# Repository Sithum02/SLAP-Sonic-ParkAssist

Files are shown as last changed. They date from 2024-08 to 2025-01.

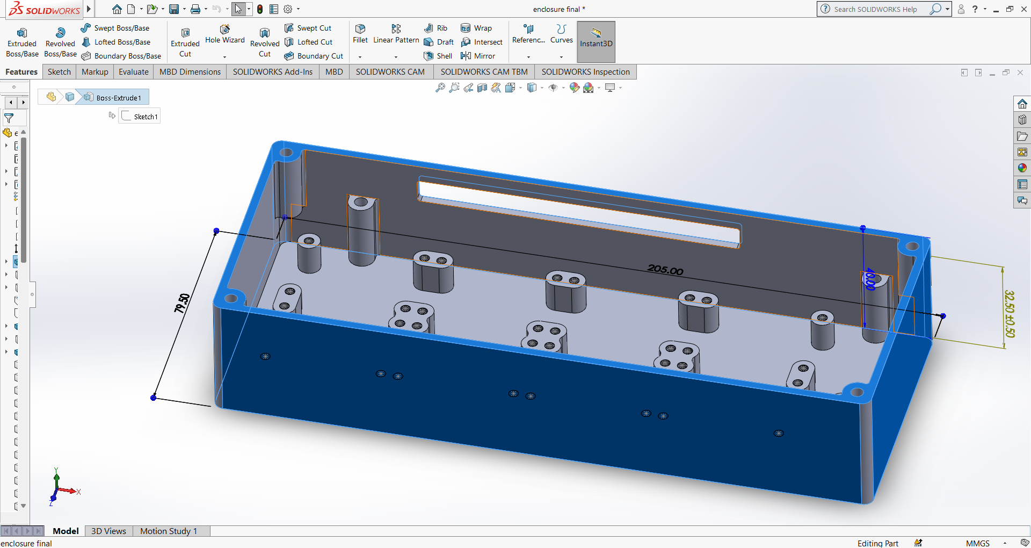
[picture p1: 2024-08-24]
Enclosure/Enclosure Screenshots/Screenshot 2024-08-24 114804.png

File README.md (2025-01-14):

# SLAPSonic ParkAssist

SLAPSonic ParkAssist is an aftermarket parking assist solution designed for vehicles that lack built-in parking sensors. The product provides distance and direction indicators using ultrasonic sensors and buzzers, offering a more intuitive and effective parking experience.

## Project Overview

The SLAPSonic ParkAssist system uses the ATmega328P microcontroller integrated with JSN-SR04T waterproof ultrasonic sensors to measure distances to obstacles and activate buzzers to alert the driver. The system is designed to be easy to install, cost-effective, and reliable for vehicles that require parking assistance.

### Key Features:
- **Microcontroller:** ATmega328P, providing the necessary computing power to handle multiple sensors and buzzers simultaneously.
- **Sensors:** JSN-SR04T waterproof ultrasonic sensors with a wide measuring range and angle.
- **Buzzers:** Active buzzers for audible alerts, with plans to introduce directional tones in future iterations.
- **Enclosure:** Custom-designed enclosure 3D printed in PLA filament, ensuring durability and sleek aesthetics.

### System Components:
- **Power Supply:** LM7805 voltage regulator for stable 12V to 5V conversion.
- **Main PCB:** The PCB connects all modules and integrates the microcontroller.
- **Sensors:** 8 JSN-SR04T sensors to measure distances from obstacles.
- **Buzzers:** Active buzzers for obstacle alerts.

## Features

- **Distance and Direction Alerts:** Provides both distance and direction information using multiple buzzers for clear guidance.
- **Waterproof Sensors:** JSN-SR04T sensors are waterproof, making them suitable for outdoor vehicle installations.
- **Compact and Reliable Design:** The product architecture is designed to reduce size and improve cost-effectiveness for wider adoption.

## Future Improvements

- **PCB Integration:** We aim to integrate the sensor modules directly into the main PCB to reduce the enclosure size and production costs.
- **Injection Molding Enclosure:** Future iterations of the enclosure will be produced using polycarbonate for improved impact and thermal resistance.
- **Microcontroller Upgrade:** Transition to STM microcontrollers for better performance and power management.

## Installation Guide

The SLAPSonic ParkAssist system is designed for easy installation:
1. Mount the ultrasonic sensors at appropriate locations on your vehicle.
2. Connect the sensors and buzzers to the main PCB.
3. Use the provided instructions to install the system and connect it to the vehicle's power supply.
4. Test the system to ensure proper functionality.

## Marketing and Sales

- **Pricing:** SLAPSonic ParkAssist will be sold at Rs. 9,999, offering a competitive and cost-effective solution compared to high-end alternatives.
- **Target Audience:** Our product is designed for drivers of older cars without built-in parking assists, as well as owners of affordable vehicles who want to upgrade their parking capabilities.

## Task Allocation

| Name | Task |
|---|---|
| Attanayake A.Y. | Circuit and PCB design, soldering and troubleshooting |
| De Zoysa A.S.I. | Enclosure design, market analysis, feasibility study |
| Goonetilleke P. | Sensor and buzzer research, microcontroller programming, testing and troubleshooting |
| Perera A.L.C.K. | Enclosure design, overseeing budget, feasibility study, and documentation |

## Budget & Pricing

The initial prototype's cost breakdown is available, with anticipated savings when scaling up production. The final product will be priced at Rs. 9,999, with profit margins aimed at covering development costs and enabling growth.

## Recycling & Disposal

To promote sustainability, we encourage recycling of the product at the end of its lifecycle. We plan to offer incentives to users who return the product’s enclosure for recycling. Detailed disposal instructions for electronic components will be provided to ensure proper environmental impact reduction.

## References

- [Real-world effects of rear automatic braking and other backing assistance systems](https://doi.org/10.1016/j.jsr.2018.12.005) - Journal of Safety Research, 2019.

## License

This project is open-source and licensed under the MIT License. Feel free to contribute and modify the project according to the license terms.

## Contact

For any questions or inquiries, feel free to reach out to the team:

- **Attanayake A.Y.**
- **De Zoysa A.S.I.**
- **Goonetilleke P.**
- **Perera A.L.C.K.**

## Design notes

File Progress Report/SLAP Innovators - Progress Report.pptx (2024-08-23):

## SLAP INNOVATORS

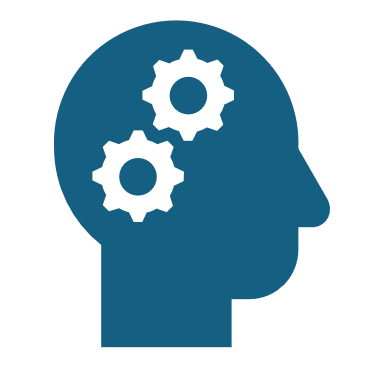
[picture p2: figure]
Head with Gears

Audio-Feedback Based Parking Assist System

## Problem Statement

Problem : Lack of blind spot coverage in most modern and older cars
Solution : Audio-Feedback based parking assist system

## Justification

Market survey results show that the problem exists

## Justification

- Survey also shows that investors are willing to invest in our product

## Task Allocation

Sithum – Designing Enclosure, Marketing
Lahiru – Designing Enclosure, Overseeing Budget
Amoda – Designing PCB, Power Supply
Pravindu – Sensors, Buzzers, and Microcontrollers

## Block Diagram

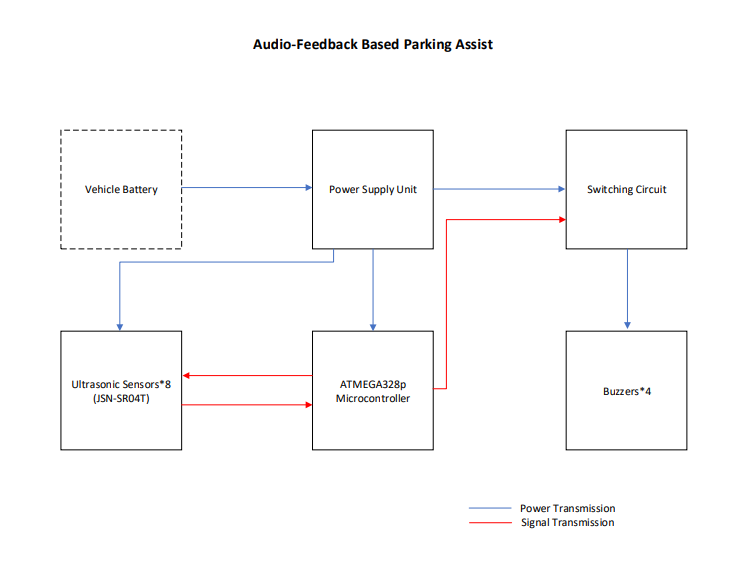
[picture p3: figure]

## Power Supply

Directly from brake lights
Maximum power consumption : (3W) 5V/0.6A

## PCB

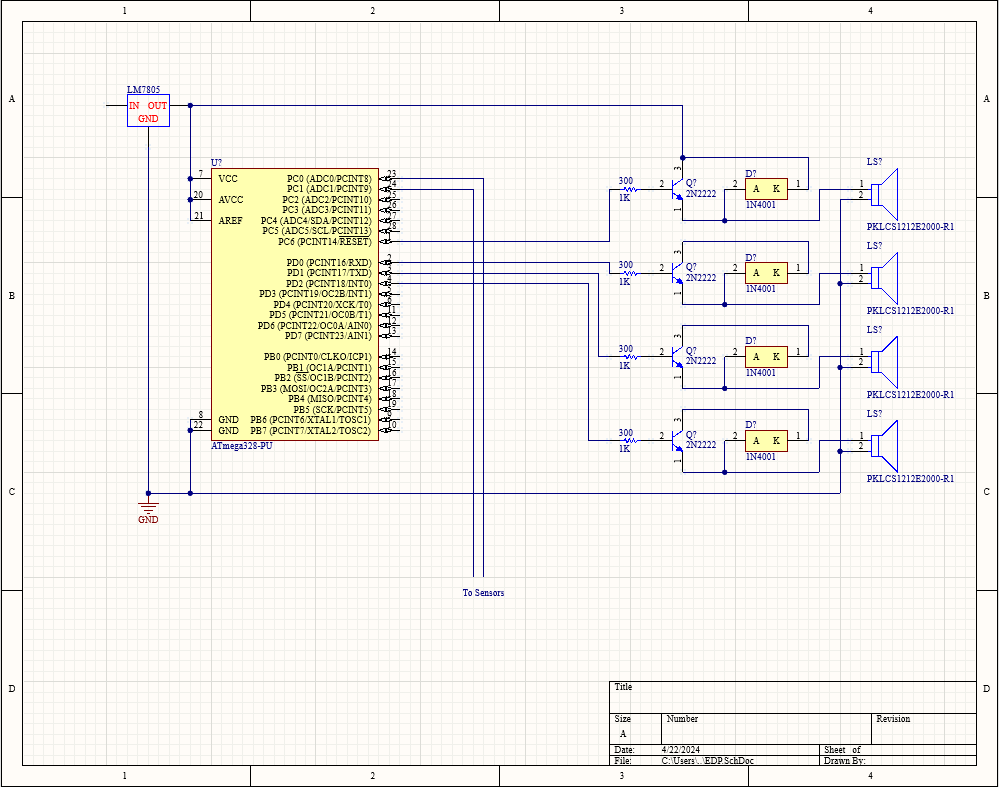
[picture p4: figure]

## Sensor

- Sensor : JSN-SR04T
- Initial testing conducted
  - Capabilities and restraints identified
  - Measurements accurate to a couple of cm
- Waterproof
- Will be attached to vehicles by drilling holes in the bumper

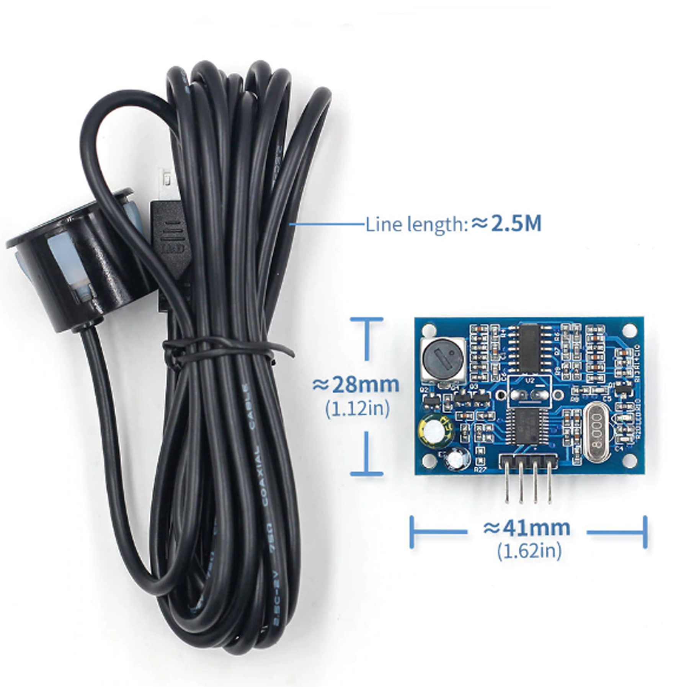
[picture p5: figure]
JSN-SR04T Waterproof Ultrasonic Sensor – Digitalelectronics.lk

## Mounting

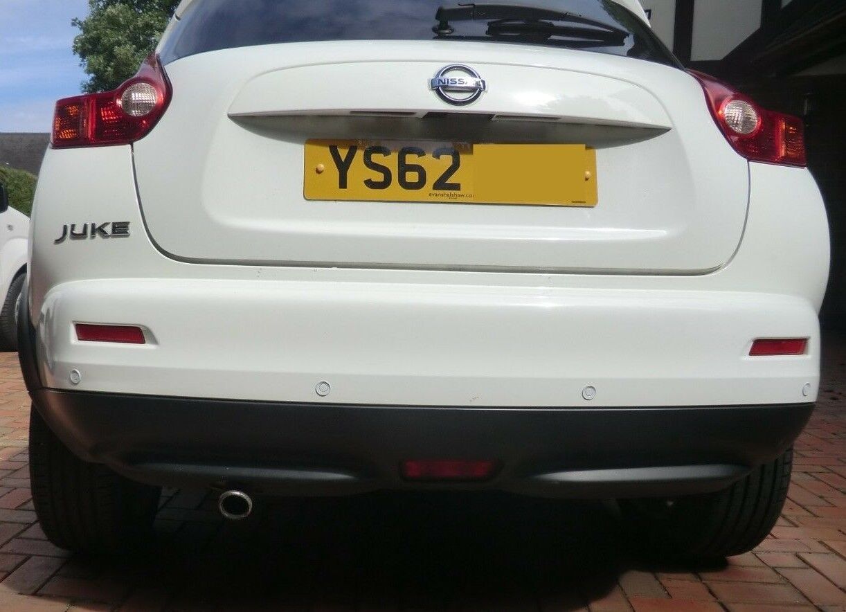
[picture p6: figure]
4 WAY REAR PARKING SENSORS NISSAN JUKE SUPPLIED & FITTED MIDLANDS AREA | eBay

## Microcontroller

- Microcontroller : ATMEGA328p
  - Low cost
  - Low power consumption
  - Sufficient i/o ports

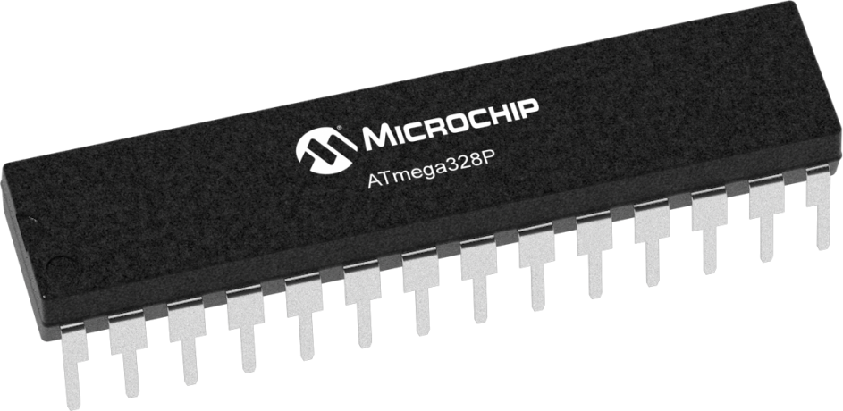
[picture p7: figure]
Programming ATmega328P with Arduino | by Krishna Ojha | Medium

## Enclosure : Initial Design

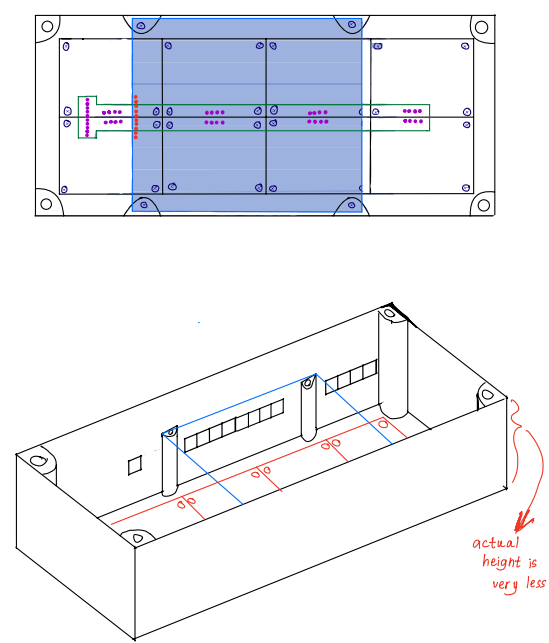
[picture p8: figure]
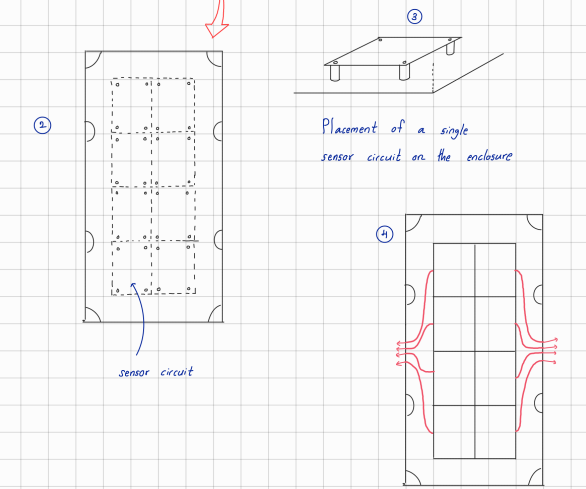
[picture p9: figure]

## Budget/BOQ

No. | Item | Qty | Rate (Without Shipping) | Total Cost
1 | JSN_SR04T | 8 | 542 | 4336
2 | ATMEGA328 | 1 | 750 | 750
3 | PCB | 2 | 250 | 500
4 | Enclosure | 1 | 2500 | 2500
5 | Buzzers | 4 | 400 | 1600
6 | Voltage Regulator | 1 | 70 | 70
| TOTAL | | | 9756

## Technical Feasibility

- Resource requirements can be met within budget
  - Bulk pricing and low-cost equipment
- Performance criteria
  - Sensors are accurate to within 1cm
  - Sensor range from 20 cm – 450 cm
  - Buzzers loud enough to be heard from all ends
  - Testing the sensor sensitivity

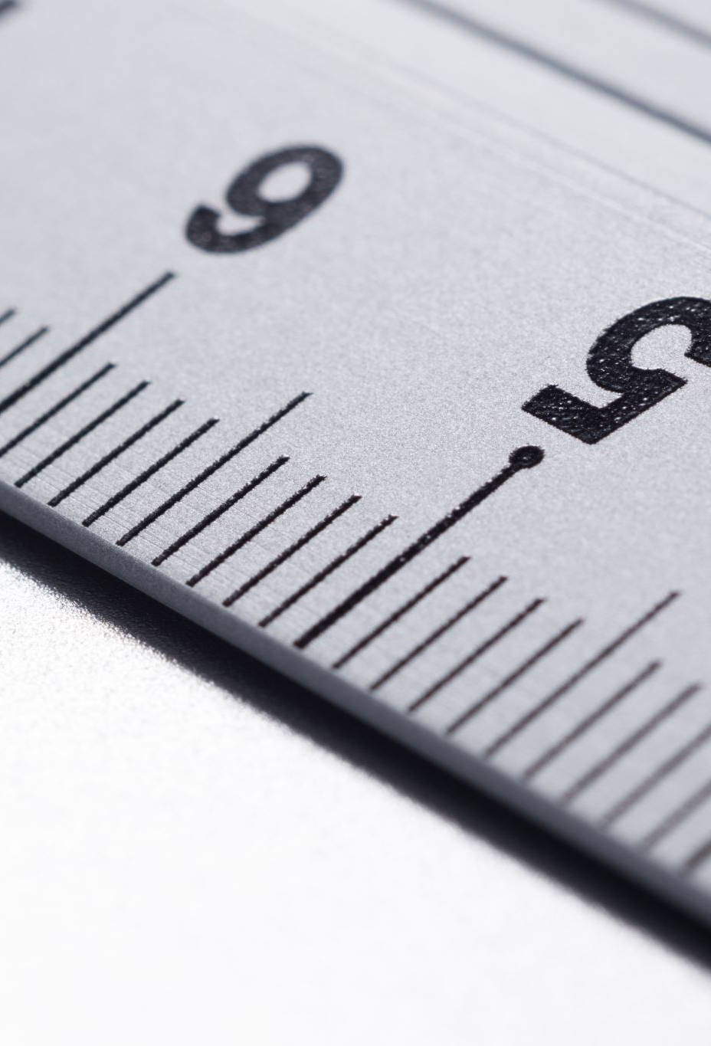
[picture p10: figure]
Close up of ruler

## Marketing and Sales Strategy

- Packaging : Matte plastic. Colors TBD.
- Through direct sales and partnerships with vehicle service stations, vehicle accessory shops etc.
- Marketing through ads on social media platforms.
- Will be made of reusable materials. Discount on next purchase for in exchange for used items older than 7 years.
- Post Sale Services
  - Repair and troubleshooting
  - 3 years warranty

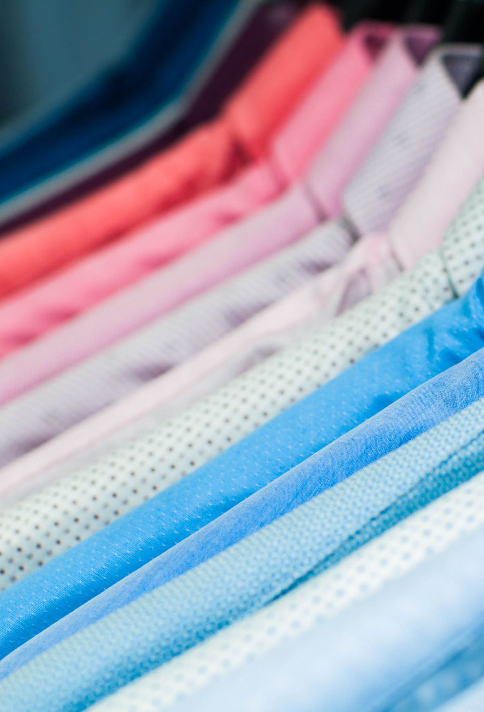
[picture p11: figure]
Multi coloured shirts hanging on the closet

## Thank You

SLAP Innovators

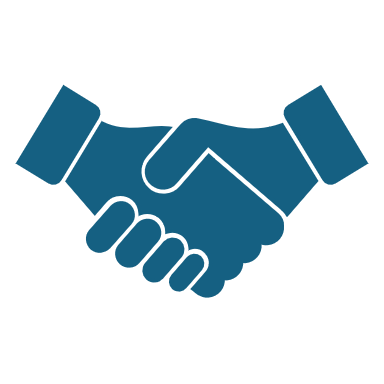
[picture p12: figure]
Handshake

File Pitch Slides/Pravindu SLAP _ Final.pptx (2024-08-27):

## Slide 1

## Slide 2

Just for
Rs. 9,999

Wide Field of View

8 Strategically placed sensors for optimal obstacle detection

4 Directional Audio Alerts

Provides intuitive driver guidance

Compact Design

Simple & easy installation in any vehicle

Lower Power Consumption

Energy efficient for sustainability

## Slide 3

Just for
Rs. 9,999

Wide Field of View

8 Strategically placed sensors for optimal obstacle detection

4 Directional Audio Alerts

Provides intuitive driver guidance

Compact Design

Simple & easy installation in any vehicle

Lower Power Consumption

Energy efficient for sustainability

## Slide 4

Wide Field of View

8 Strategically placed sensors for optimal obstacle detection

4 Directional Audio Alerts

Provides intuitive driver guidance

Compact Design

Simple & easy installation in any vehicle

Lower Power Consumption

Energy efficient for sustainability

Just for
Rs. 9,900

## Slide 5

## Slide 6

Wide Field of View

8 Strategically placed sensors for optimal obstacle detection

4 Directional Audio Alerts

Provides intuitive driver guidance

Compact Design

Simple & easy installation in any vehicle

Lower Power Consumption

Energy efficient for sustainability

Just for
Rs. 9,900

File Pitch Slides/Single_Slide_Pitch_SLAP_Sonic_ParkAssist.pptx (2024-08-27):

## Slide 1

Wide Field of View

8 Strategically placed sensors for optimal obstacle detection

4 Directional Audio Alerts

Provides intuitive driver guidance

Compact Design

Simple & easy installation in any vehicle

Lower Power Consumption

Energy efficient for sustainability

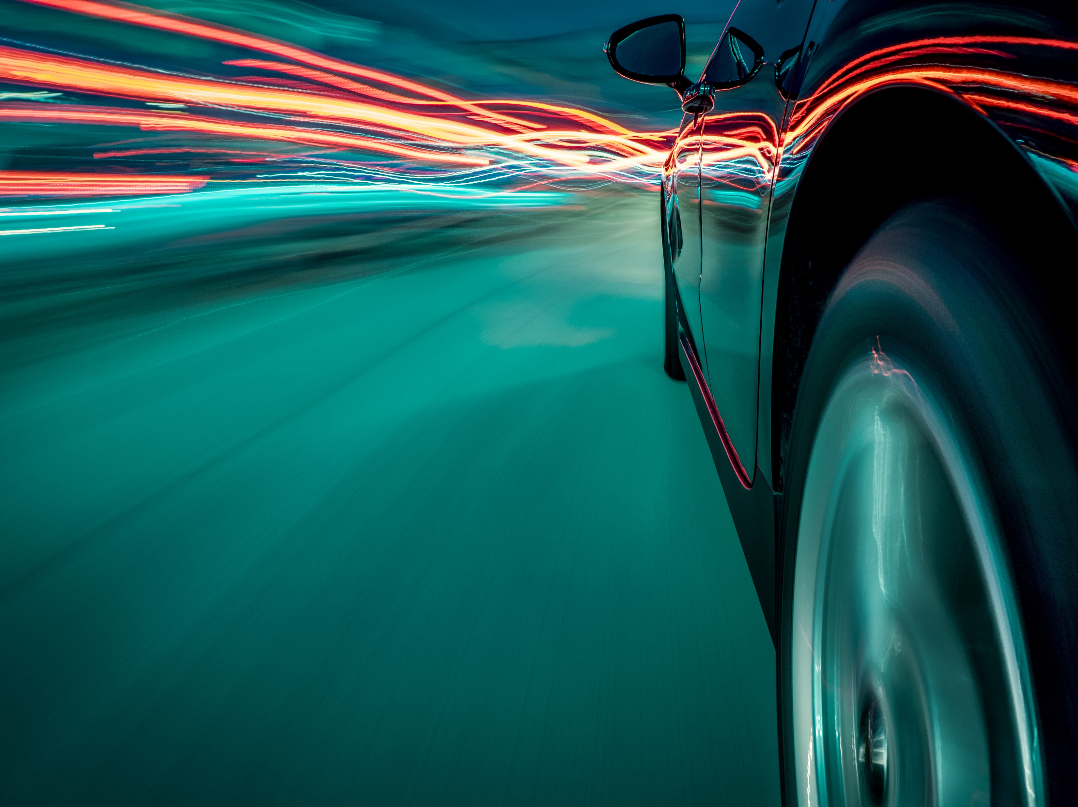
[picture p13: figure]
Long-exposure photo of car in traffic
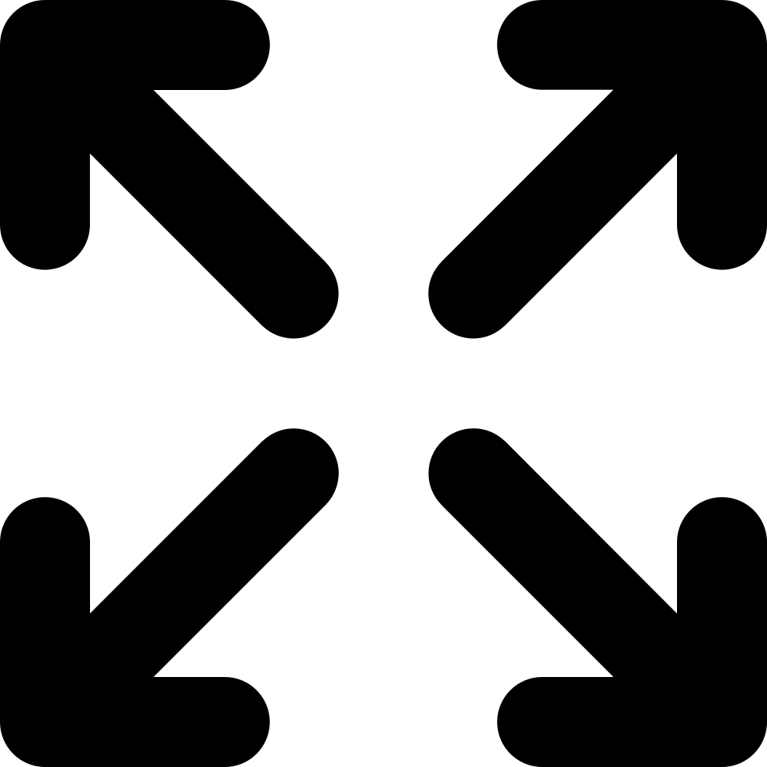
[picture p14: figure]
Font,Line,Clip art,Hand,Graphics,Symbol,Gesture #141486 - Free Icon Library
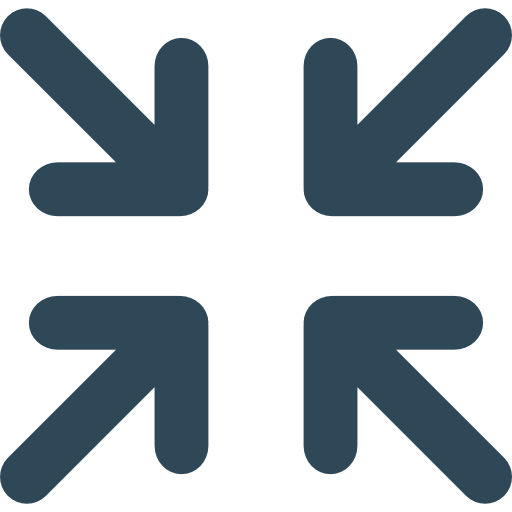
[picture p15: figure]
Anurav Hydronics
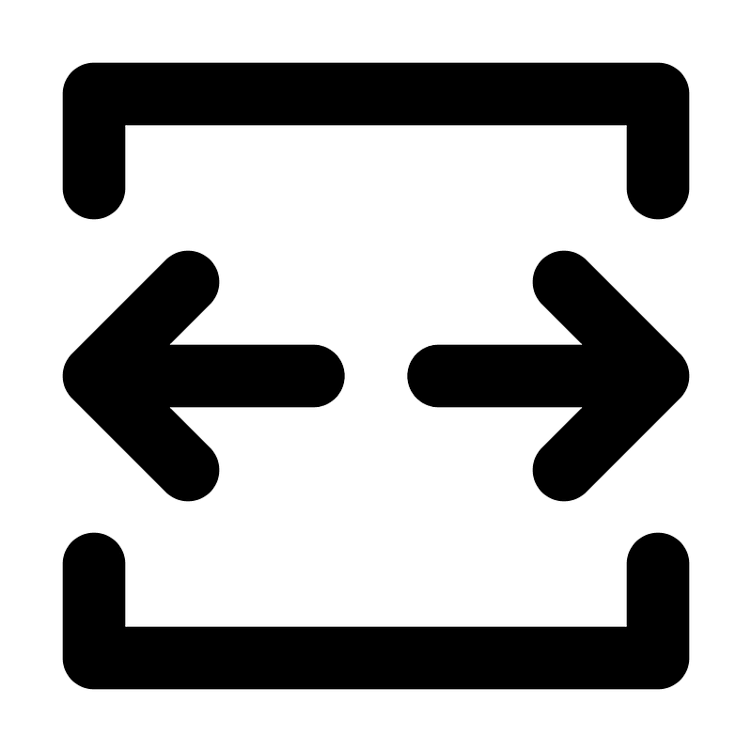
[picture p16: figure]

Just for
Rs. 9,900

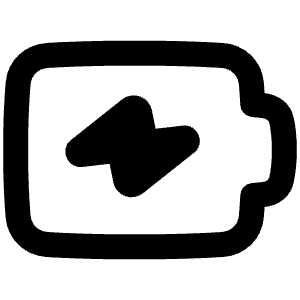
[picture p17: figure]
Battery Charging icon from Plump Remix - Free Set | Free Download as ...

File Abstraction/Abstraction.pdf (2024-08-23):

Power Supply Unit

ATMEGA328p
Microcontroller

Ultrasonic Sensors*8
(JSN-SR04T) | Buzzers*4
Vehicle Battery | Switching Circuit

## Audio-Feedback Based Parking Assist

Power Transmission
Signal Transmission

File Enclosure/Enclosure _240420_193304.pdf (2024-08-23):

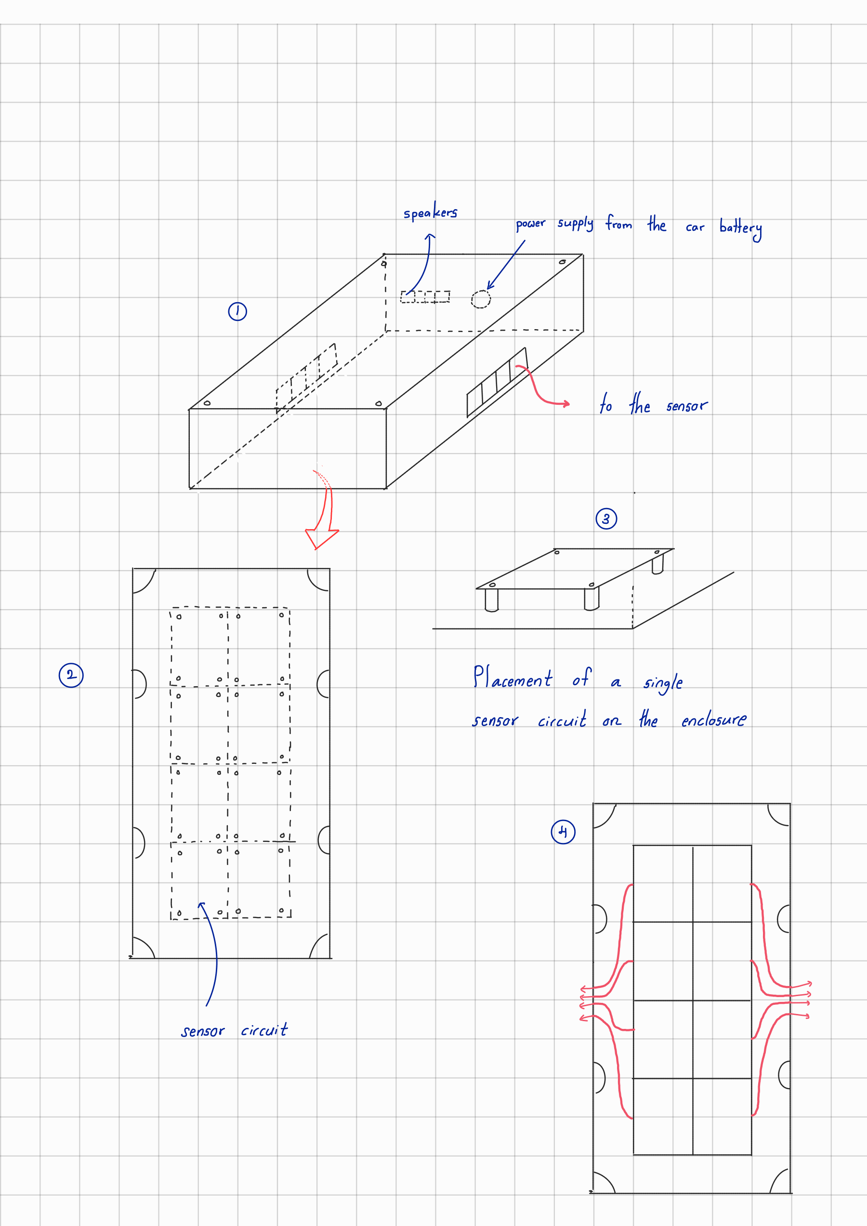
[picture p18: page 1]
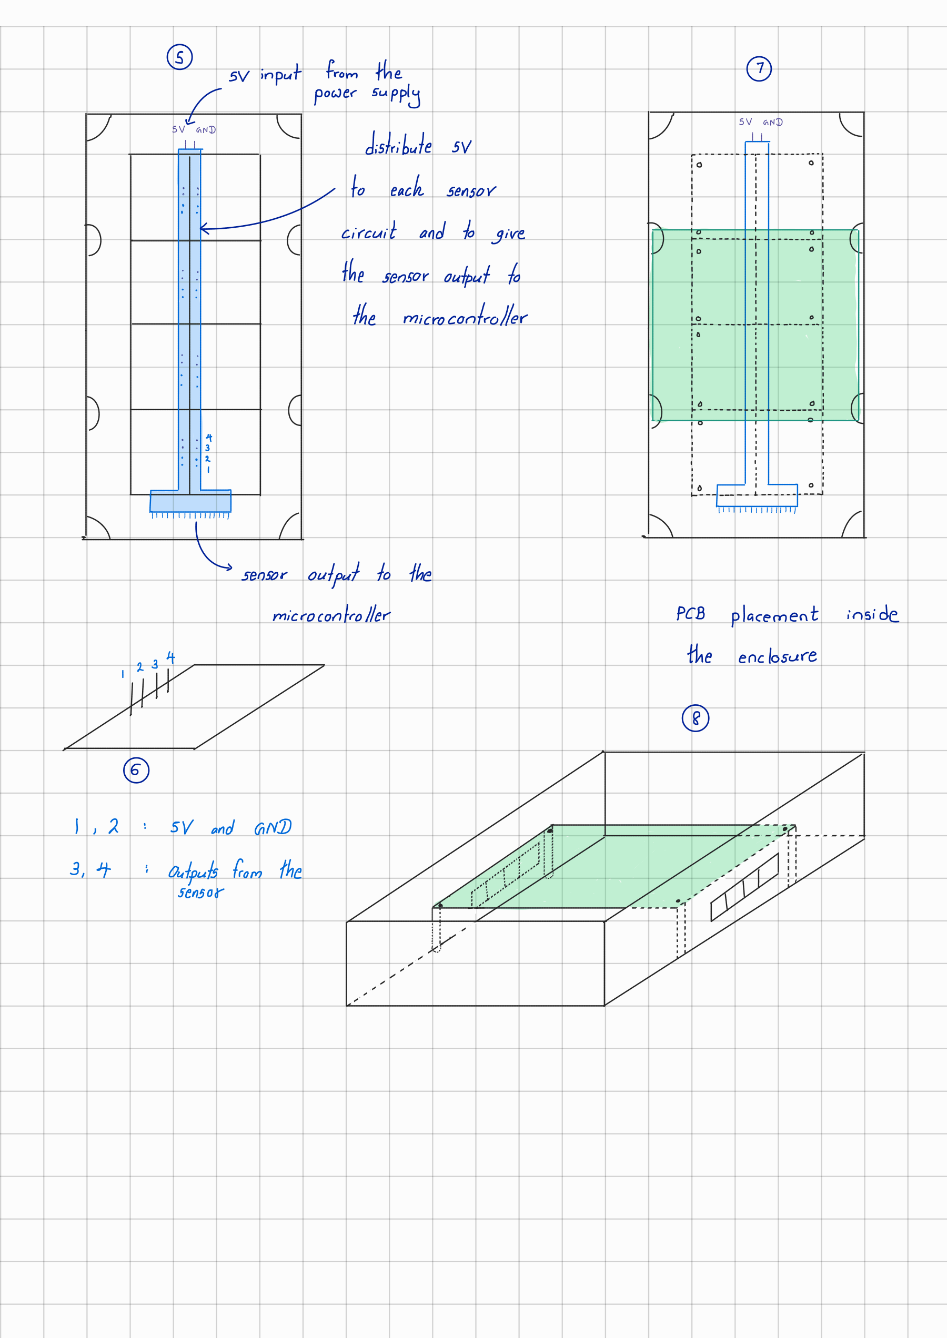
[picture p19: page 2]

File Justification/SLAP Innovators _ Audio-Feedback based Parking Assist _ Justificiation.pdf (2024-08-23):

SLAP Innovators

Justification for the Audio-Feedback based Parking Assist

Introduction

In the realm of automotive safety, the issue of blind spots poses a significant concern. Despite the presence of mirrors, certain areas around a vehicle remain unseen, potentially leading to accidents involving pedestrians or objects. While parking cameras have been introduced to mitigate this risk, their efficacy in reducing accidents remains limited, with a mere 5% improvement. Conversely, integrating parking assist systems has shown a remarkable 42% reduction in parking-related incidents.

Recognizing a gap in the market, particularly among older generation vehicles lacking built-in proximity sensors, our solution aims to address this safety concern. Existing external proximity sensor options typically lack auditory feedback, presenting a challenge for drivers navigating parking and congested traffic situations. Our product offers a tailored solution - an audio-feedback based parking assist system, adaptable to vehicles without built-in proximity alarms.

Functionality

Powered by the vehicle's battery, our system triggers a buzzer or siren when the vehicle nears a solid object. The alarm distance is customizable during installation to suit individual preferences. Four sirens/buzzers positioned at each corner of the vehicle activate upon detecting a barrier, intuitively guiding the driver away from potential hazards.

Justification

Conducting thorough market research, we discovered a prevalent need for parking assistance among respondents.

0.00%

10.00%

20.00%

30.00%

40.00%

50.00%

60.00%

70.00%

80.00%

90.00%

Yes | No | Yes | No
Does your car have Parking Assist | Does your car have Blind Spots

### Current State of Safety Features

The survey overwhelmingly favored the implementation of parking assist systems for both parking and navigating congested traffic scenarios, irrespective of whether they had experienced accidents due to blind spots.

Our survey also revealed a clear preference for audio-feedback based systems, with a significant amount of respondents being willing to invest between Rs. 8,000 and Rs. 10,000. This aligns seamlessly with our product's offerings and market positioning.

0.00%

20.00%

40.00%

60.00%

80.00%

100.00%

120.00%

Yes | No | Yes | No | Yes | No

Have you ever met with an
accident while parking, due
to these blind spots?

Do you think a parking
assist system could help in parking?

Do you think proximity
based parking assists could help to navigate when
stuck in heavy traffic?

### Requirement of a Parking Assist System

0.00%

10.00%

20.00%

30.00%

40.00%

50.00%

60.00%

70.00%

80.00%

90.00%

100.00%

Yes | No

Would you prefer the parking assist to indicate the direction of proximity through speakers placed in the corresponding directions?

### Preferred Assist System

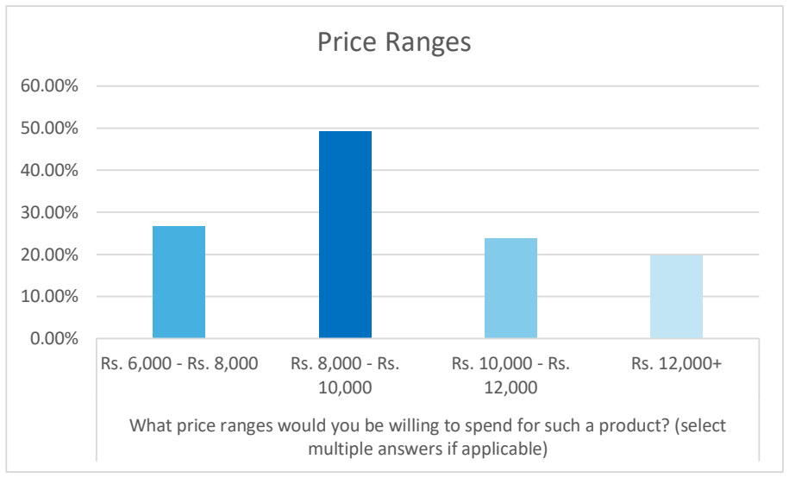
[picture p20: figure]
multiple answers if applicable); Price Ranges

In summary, the demand for our audio-feedback based parking assist system, along with the willingness of consumers to invest in such technology, highlights the tangible market potential for our product.

SLAP Innovators

1. A. Y. Attanayake 220051D
2. A. S. I. De Zoysa 220106D
3. P. Goonetilleke 220183H
4. A. L. C. K. Perera 220495K

What price ranges would you be willing to spend for such a product? (select

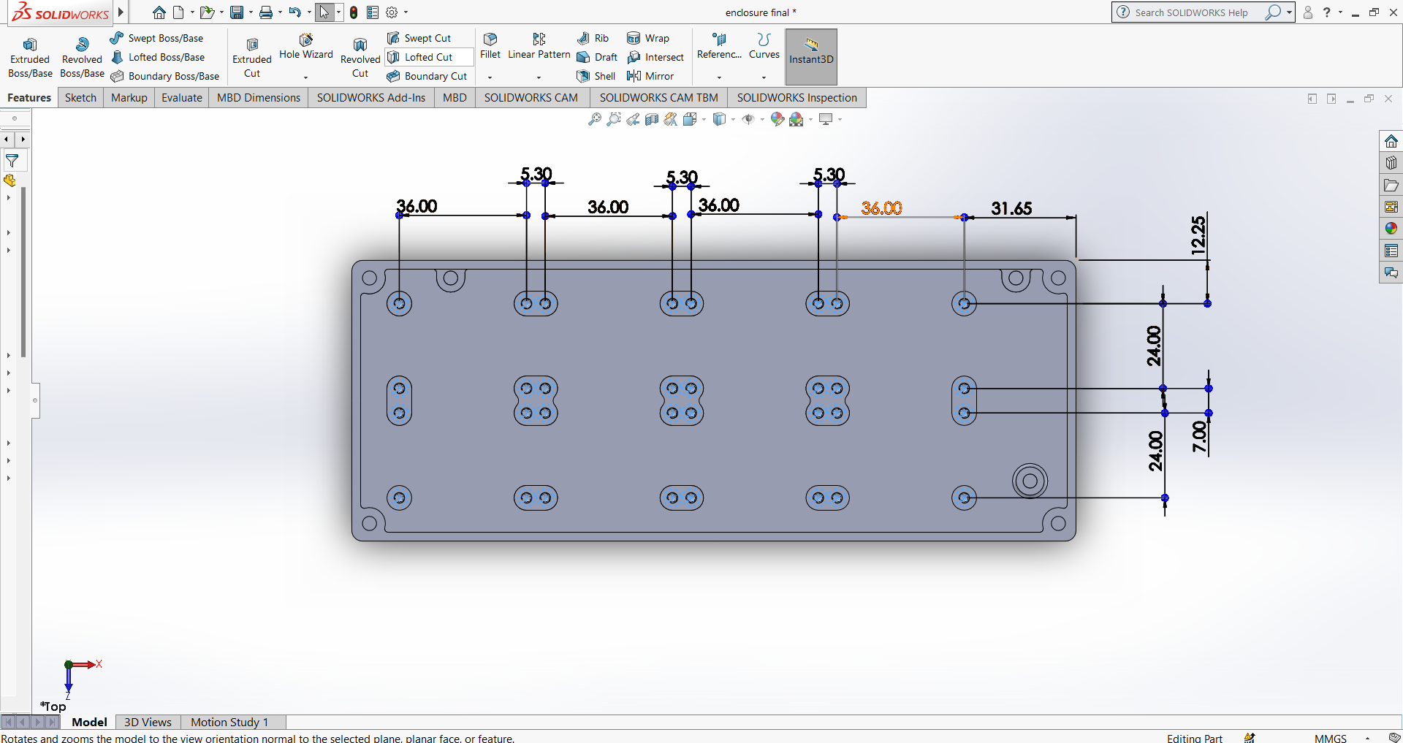
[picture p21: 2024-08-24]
Enclosure/Enclosure Screenshots/Screenshot 2024-08-24 115512.png

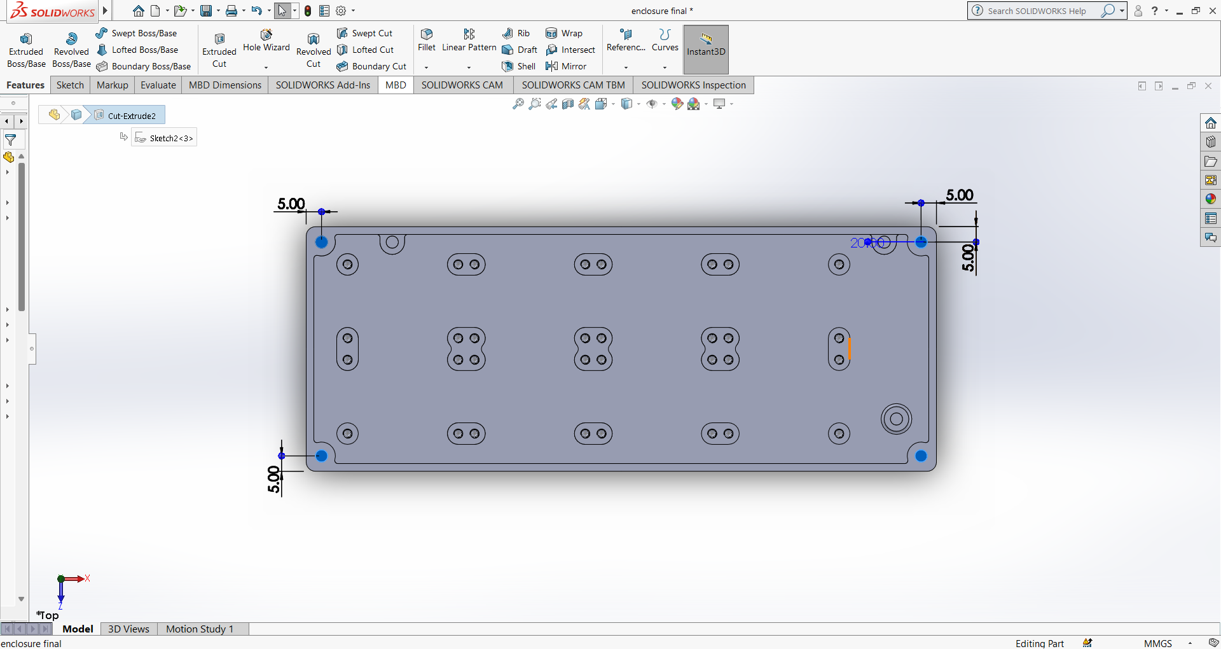
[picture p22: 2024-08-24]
Enclosure/Enclosure Screenshots/Screenshot 2024-08-24 115445.png

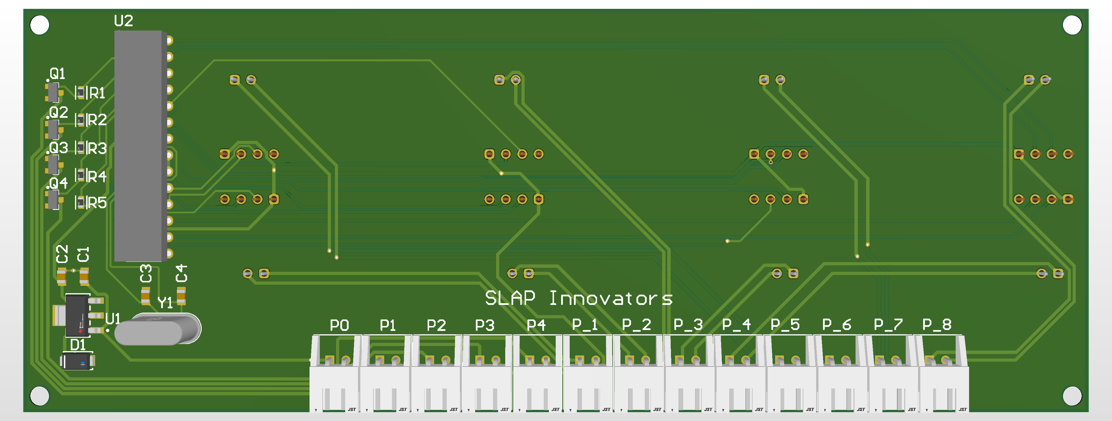
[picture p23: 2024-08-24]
PCB/PCB-Top.png

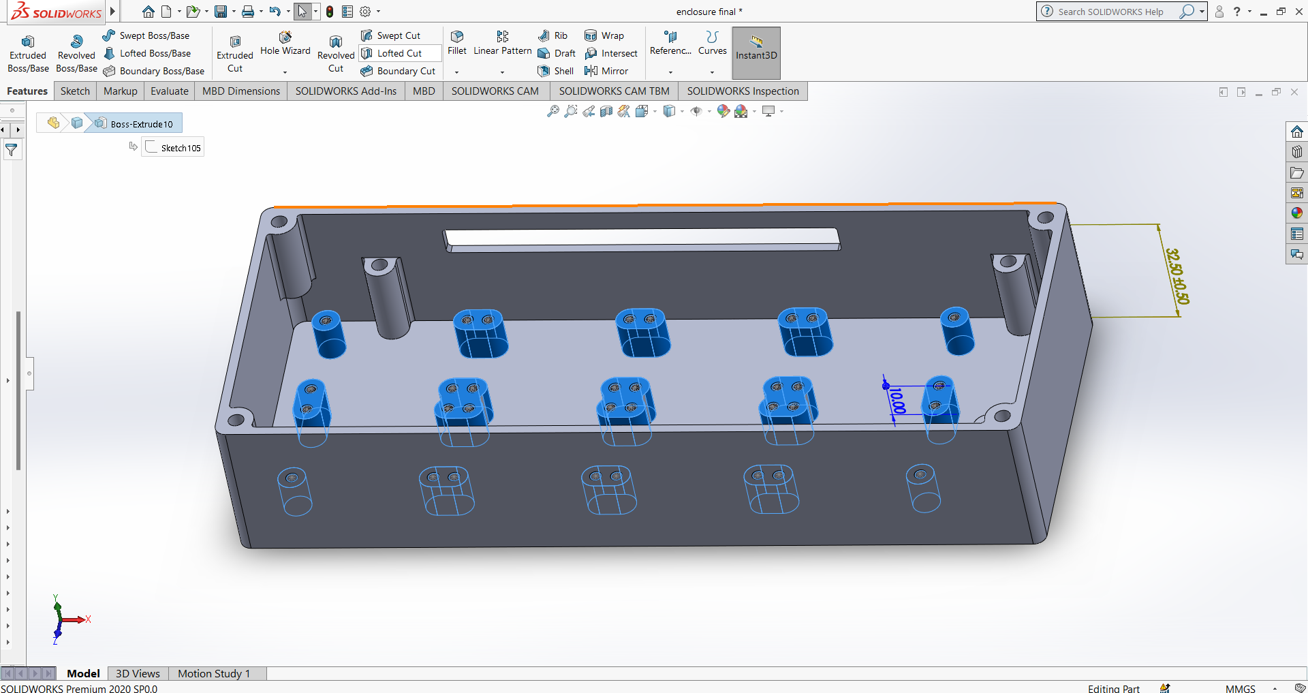
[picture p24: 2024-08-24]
Enclosure/Enclosure Screenshots/Screenshot 2024-08-24 115649.png

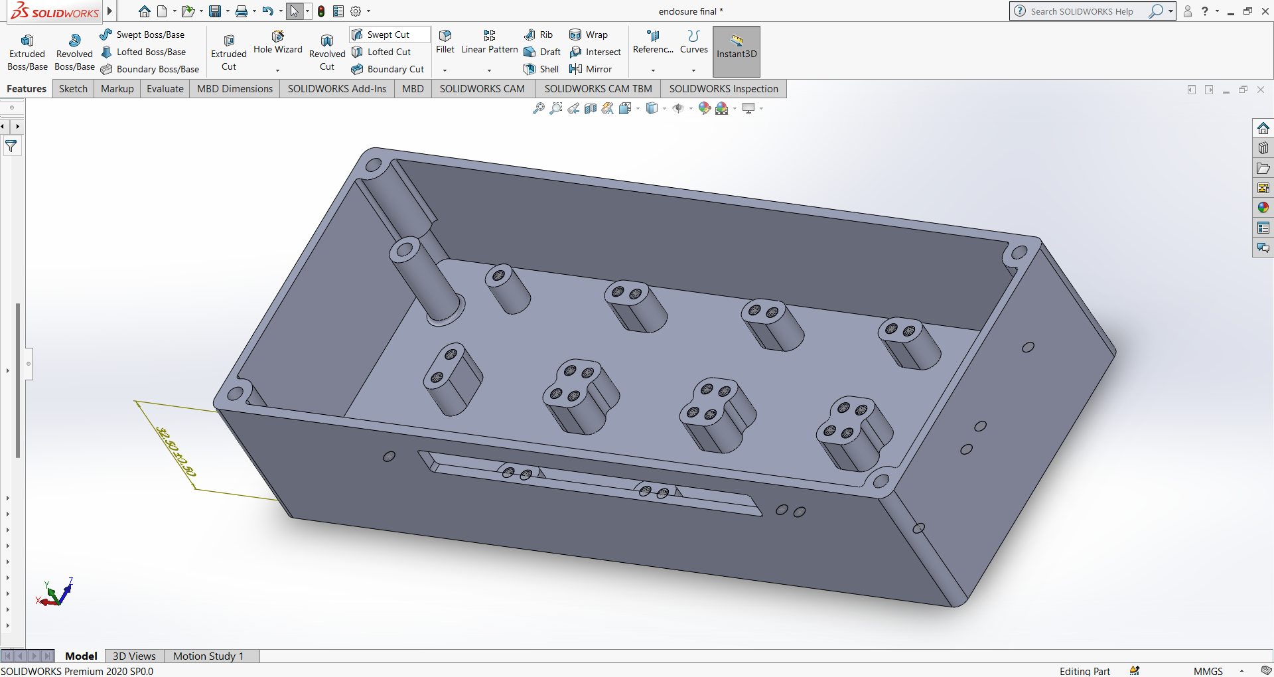
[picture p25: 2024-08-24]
Enclosure/Enclosure Screenshots/Screenshot 2024-08-24 115857.png

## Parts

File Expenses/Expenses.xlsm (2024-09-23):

Name | Item | Cost/Unit | Amount | Price
Pravindu | JSN-SR04T | 1500 | 1 | 1500
Pravindu | Parking Kit https://www.daraz.lk/products/04-led-parking-sensor-i972138-s2928750.html?search=1 | 2735 | 1 | 2735 | Member | Amount Spent | Amount Due
Pravindu | ATMEGA328p - duino.lk | 1870 | 1 | 1870 | Pravindu | 36316.81 | -22548.095
Pravindu | JSN SR04Thttps://www.daraz.lk/products/ultrasonic-sensor-waterproof-jsn-sr04t-arduino-i175847552-s1134882298.html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 | 8636.81 | 1 | 8636.81 | Amoda | 14608.05 | -839.335
Pravindu | JSN SR04T Senith | 1750 | 10 | 17500 | Lahiru | 4150 | 9618.715
Amoda | Components - eTusker | 570 | 1 | 570 | Sithum | 0 | 13768.715
Amoda | Connectors - https://www.daraz.lk/products/10sets-jst-xh254-xh-254mm-wire-cable-connector-2345678910-pin-pitch-male-female-plug-socket-20cm-wire-length-26awg-i198445089.html | 712 | 2 | 1424
Amoda | Components - Pitakotuwa | 90 | 1 | 90
Pravindu | Components - pitakotuwa | 265 | 1 | 265
Pravindu | ATMEGA328p - https://tronic.lk/product/atmel-atmega328p-pu-microcontroller-with-uno-boot-loade | 900 | 3 | 2700
Pravindu | 4 pin connectors -https://tronic.lk/product/long-4-way-pcb-mount-wire-clip-with-socket-xh-4px-300mm | 30 | 8 | 240
Amoda | PCBs | 605 | 5 | 3025
Amoda | PCB shipping | 460 | 5 | 2300
Amoda | PCBs | 393.41 | 5 | 1967.04
Amoda | PCB shipping | 915.72 | 5 | 4578.6
Amoda | Connectors - https://www.aliexpress.com/item/32817036250.html | 6.07 | 50 | 303.41
Amoda | 2 pin connectors | 35 | 10 | 350
Lahiru | Enclosure | 4150 | 1 | 4150
Pravindu | Wires | 870 | 1 | 870
 |  |  |  | 0
 |  |  |  | 0
TOTAL |  |  |  | 55074.86
Amount per person |  |  |  | 13768.715

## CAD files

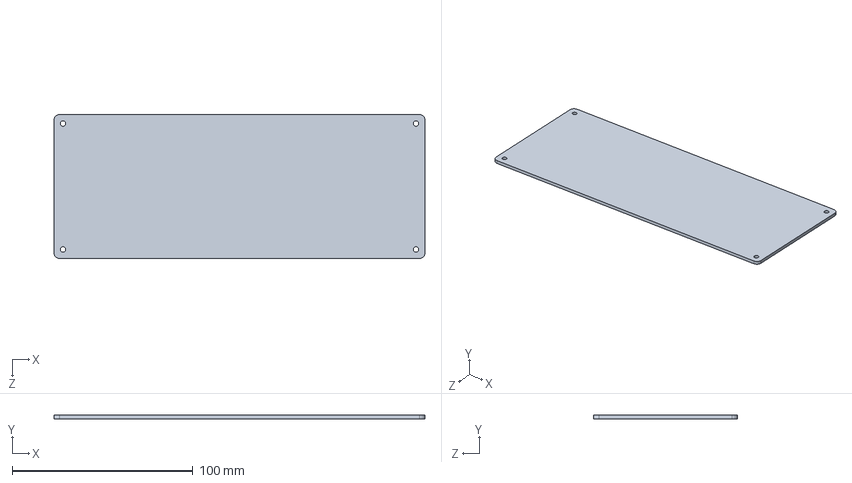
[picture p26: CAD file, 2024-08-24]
Enclosure/enclosure lid.SLDPRT
205.0 x 2.00 x 79.5 mm

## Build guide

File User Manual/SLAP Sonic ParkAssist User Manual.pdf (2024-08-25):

S

L

A

### P In

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
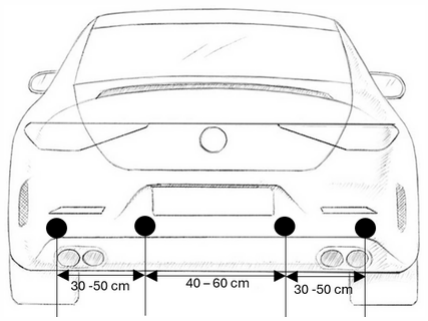
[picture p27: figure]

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
# nic

P

a

r

k
A

s

# sis

# t Installation Guide *Power supply can be connected

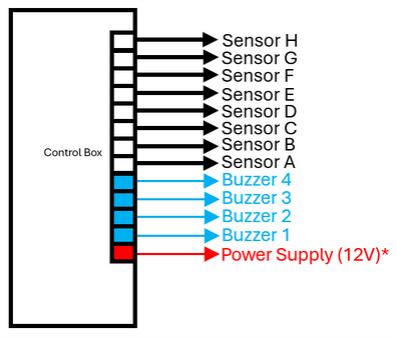
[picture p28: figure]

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
e lig

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
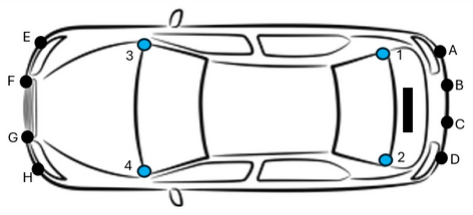
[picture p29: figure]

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
r. Before drilling bumper, ensure there is sufficient clearance (approx 25mm will be required) First, insert the wire into the hole and drag through till the sensor sits in the hole

T

e

c

h

## nic

## al D

e

t

## ails

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
## ails

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
alid

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
y in

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
ol box will void warranty Any physical/water damage to control box will void warranty

H

## elp

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
## Pla

n

e

t! The control box is fully recyclable. R

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
ol b

o

x

t

o

S

L

A

P In

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
f lifetime for a discount on future purchases! Do Not Dispose of in Trash: This product contains electronic components and should not be discarded with household waste. (contains materials such as lead.) Recycle as e-Waste: Please recycle the circuit board at a designated electronic waste (e-waste) recycling facility. Environmental Impact: Improper disposal can harm the environment. Recycling recovers valuable materials and reduces pollution. Or simply return the PCB along with the control box! Disposal of Circuit Board

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
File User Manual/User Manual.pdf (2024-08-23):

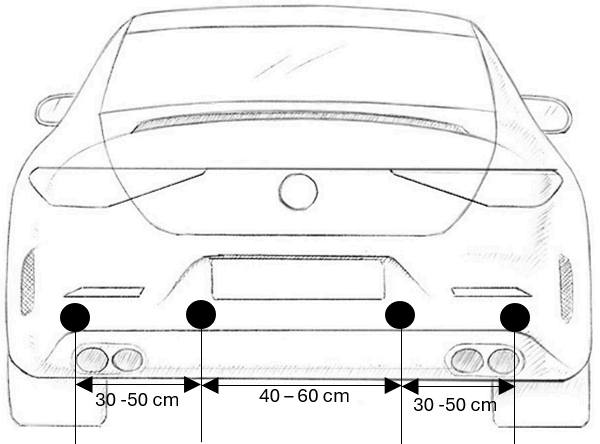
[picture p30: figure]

### SLAP Innovators

Rated Voltage | 12V
Operating Voltage | 9-16V
Rated current | 372 mA
Detecting Range | 20-80cm
Ultrasonic Frequency | 40kHz

# Parking Assist Kit

## Installation Guide

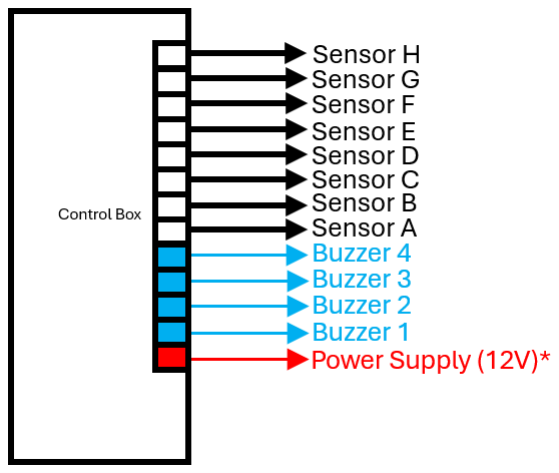
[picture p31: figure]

*Power supply can be connected to Battery through toggle switch - Active when toggled
Reverse lights - Active when reversing

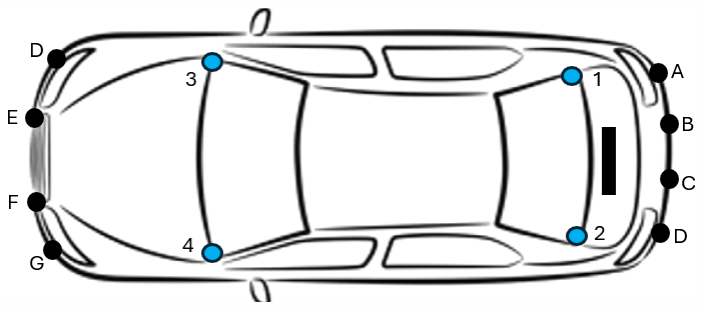
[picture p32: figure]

Sensors should by 40-70 cm above the ground
Sensors should be spaced between 30 and 60 cm apart from each other Before drilling bumper, ensure there is sufficient clearance (approx 25mm will be required)

## Technical Details

## Warranty Details

Warranty valid for 6 months from date of purchase
Any indication of attempt to open control box will void warranty
Any physical/water damage to control box will void warranty

## Help us save the Planet!

The control box is fully recyclable. Return control box to SLAP Innovators at end of lifetime for a discount on future purchases!

Do Not Dispose of in Trash: This product contains electronic components and should not be discarded with household waste. (contains materials such as lead.
Recycle as e-Waste: Please recycle the circuit board at a designated electronic waste (e-waste) recycling facility. Environmental Impact: Improper disposal can harm the environment. Recycling recovers valuable materials and reduces pollution.
Or simply return the PCB along with the control box!

## Disposal of Circuit Board

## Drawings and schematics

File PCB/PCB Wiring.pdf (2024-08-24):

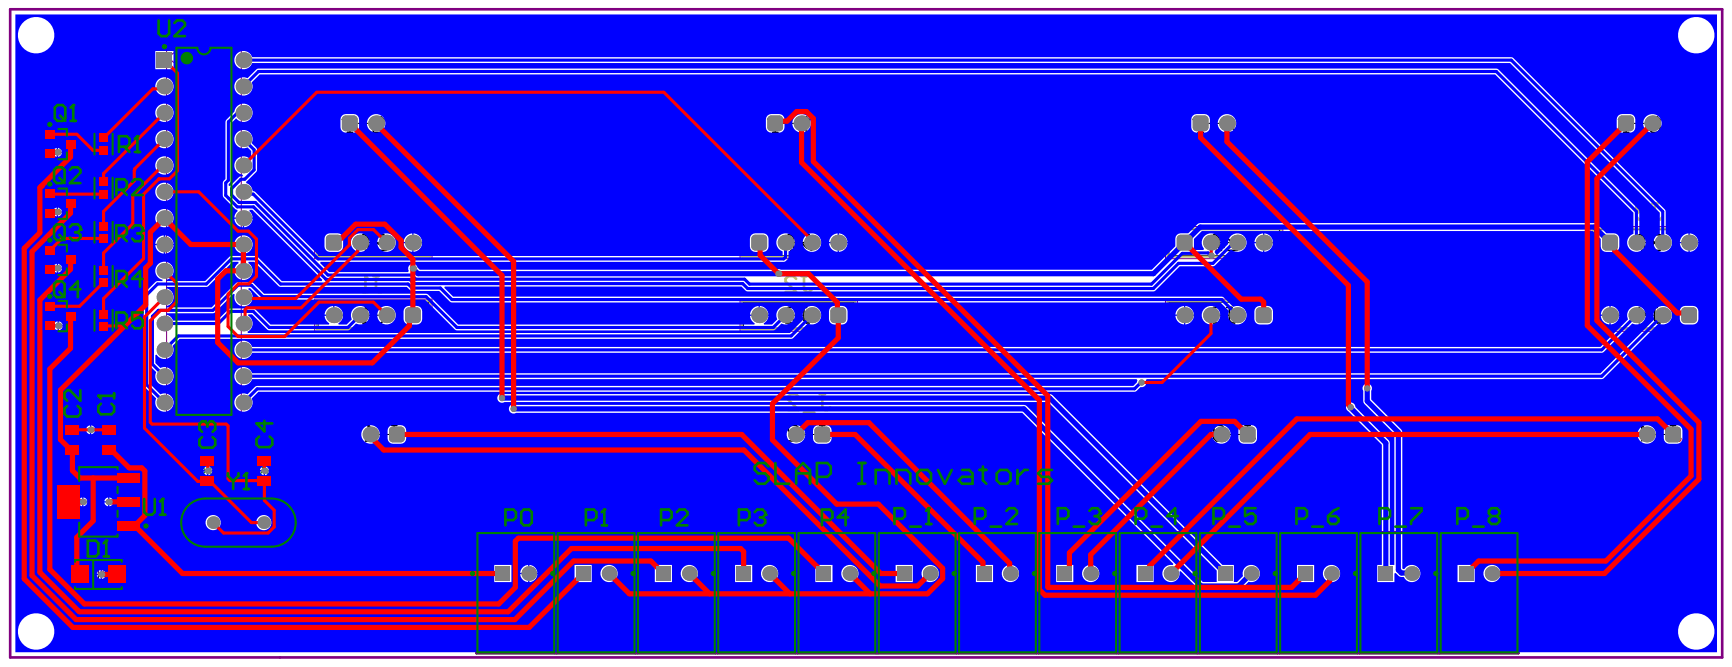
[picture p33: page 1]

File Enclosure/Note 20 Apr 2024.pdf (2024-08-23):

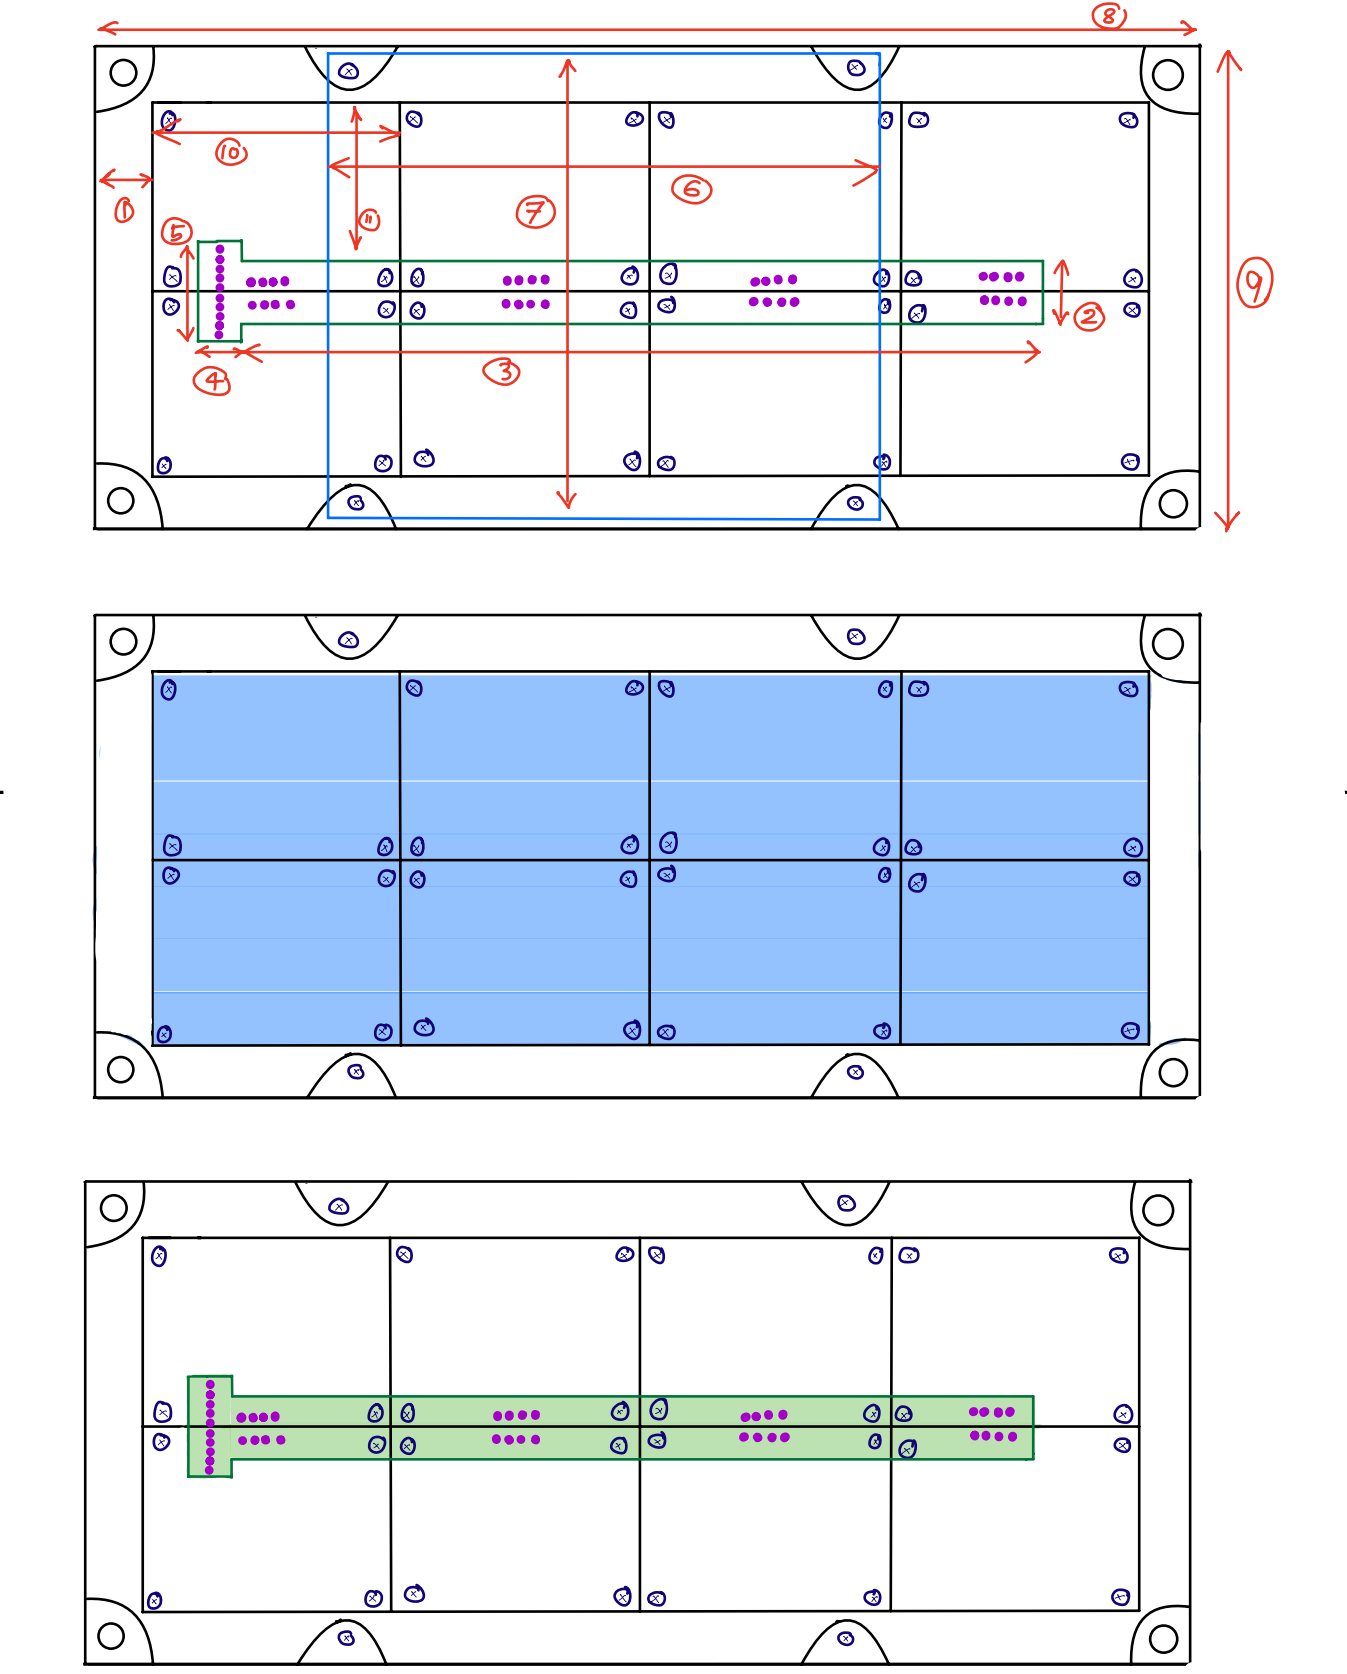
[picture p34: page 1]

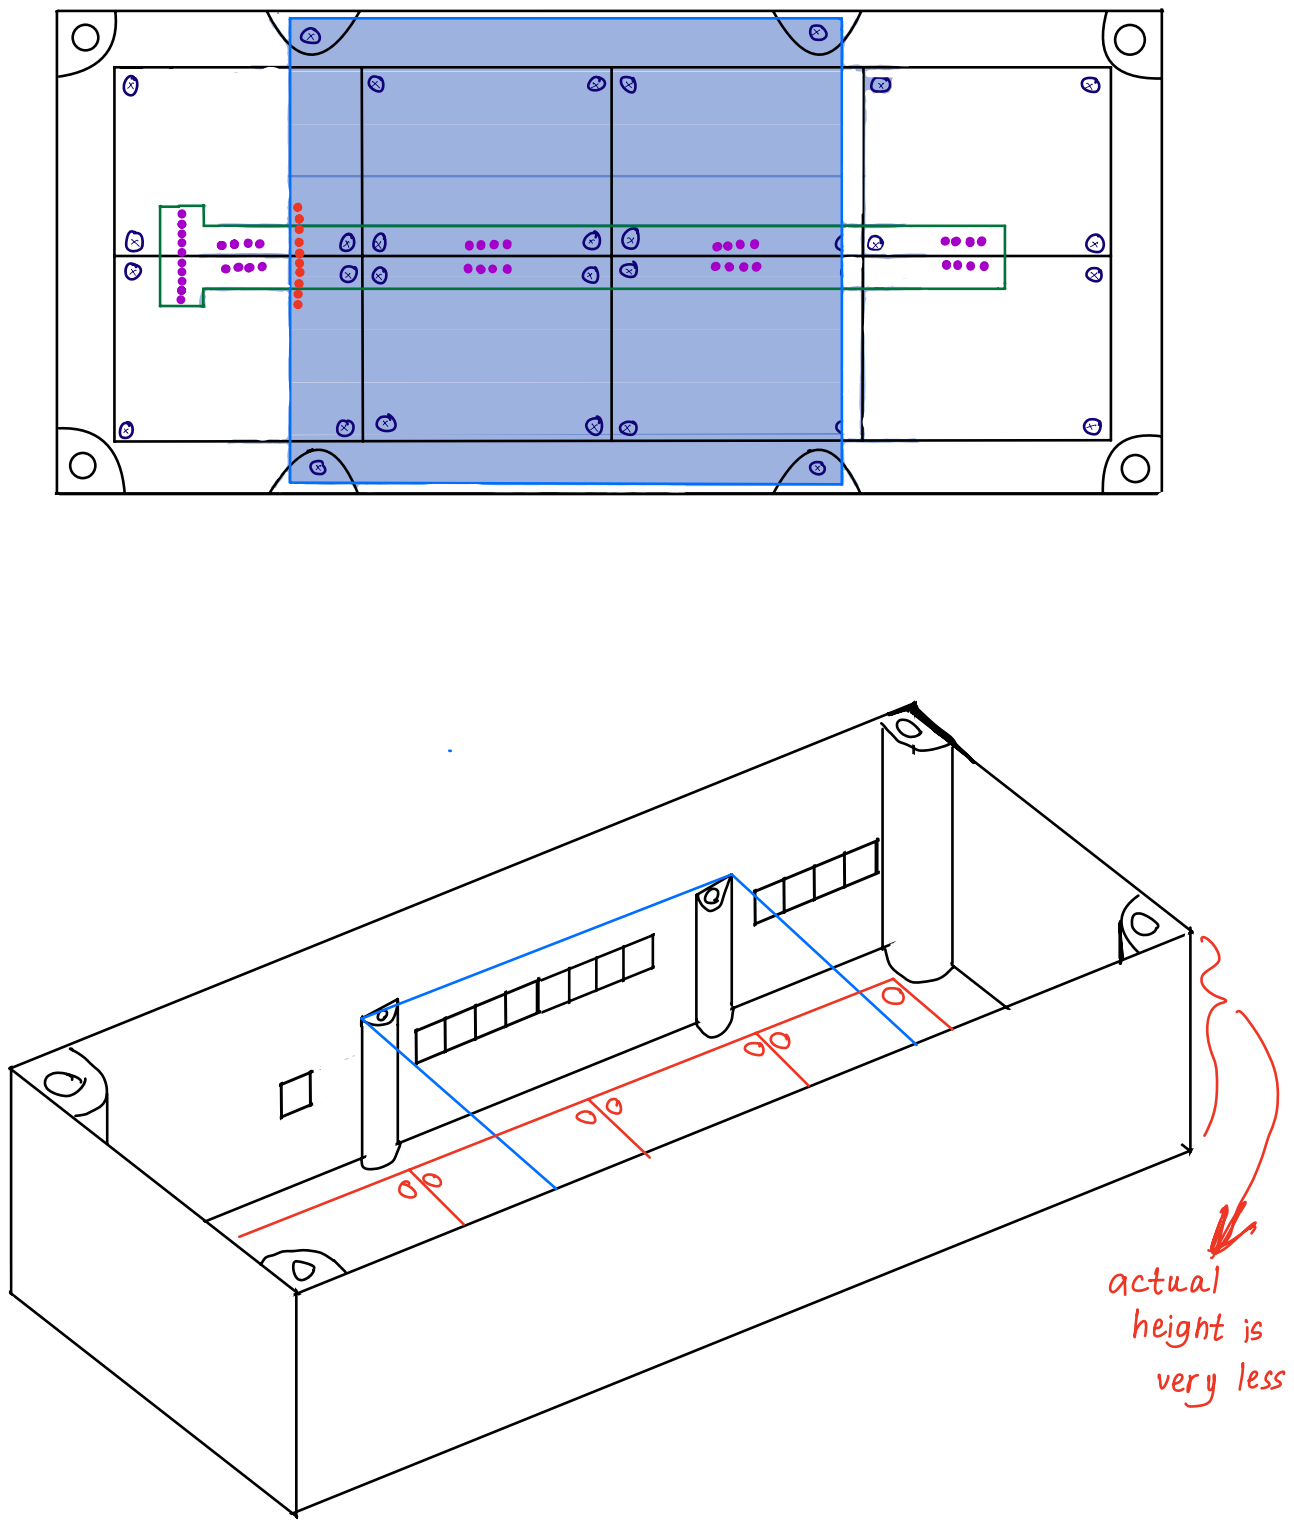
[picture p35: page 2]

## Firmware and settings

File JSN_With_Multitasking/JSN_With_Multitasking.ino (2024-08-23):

// Define the class
const int MAX_DIST = 4665;
const int MAX_DELAY = 750;
unsigned long current_time_sensor = 0;
unsigned long current_time_buzzer = 0;


class Sensor {
public:
  int id;
  int trigPin;
  int echoPin;
  long duration;
  int distance;
  unsigned long previous_time_sensor = 0;

  // Constructor
  Sensor(int id, int trig, int echo) {
    this->id = id;
    this->trigPin = trig;
    this->echoPin = echo;
  }

  // Method to get distance
  int getDistance() {
    return this->distance;
  }

  void setPins() {
    pinMode(this->trigPin, OUTPUT);
    pinMode(this->echoPin, INPUT);
  }

  // Method to trigger sensor
  void trigger() {
    // Clears the trigPin
    digitalWrite(this->trigPin, LOW);
    if (current_time_sensor - this->previous_time_sensor > 2) {
      // Sets the trigPin on HIGH state for 10 micro seconds
      digitalWrite(this->trigPin, HIGH);
      this->previous_time_sensor = current_time_sensor;
      if (current_time_sensor - this->previous_time_sensor > 10) {
        digitalWrite(this->trigPin, LOW);
      }
    }


    // Reads a pulse (either HIGH or LOW) on a pin. For example,
    // if value is HIGH, pulseIn() waits for the pin to go from LOW to HIGH, starts timing, then waits for the pin to go LOW and stops timing.
    // Returns the length of the pulse in microseconds or gives up and returns 0 if no complete pulse was received within the timeout.
    this->duration = pulseIn(this->echoPin, HIGH, 30000);

    // Constraining the values within the required limit
    //this->duration = constrain(this->duration, 1068, MAX_DIST);

    // Mapping each duration to an BuzzerLevel, while inverting it
    // BuzzerLevel = map(duration, 250, 1000, 255, 0);
    this->distance = this->duration / 2 * 343 / 10000;
    if (this->distance == 0) {
      this->distance = 80;
    }

    // this->display();
  }

  // Method to display distance and activate speakers
  // void display() {
  //   if (this->distance != 183) {
  //     Serial.print(this->id);
  //     Serial.print(": ");
  //     Serial.println(this->distance);
  //   }
  // }
};

class Buzzer {
public:
  int id;
  int pin;
  unsigned long buzzer_delay;
  unsigned long previous_time_buzzer = 0;

  //Constructor
  Buzzer(int id, int pin) {
    this->id = id;
    this->pin = pin;
  } 

  void setPins() {
    pinMode(this->pin, OUTPUT);
  }

  void setDelay(int sensor_1_dist, int sensor_2_dist) {
    // Select the closest  distance
    int distance = min(sensor_1_dist, sensor_2_dist);

    // Constrain the distane
    distance = constrain(distance, 20, 80);
    // Serial.print(distance);
    // Serial.print(" ");
    // Serial.println(this->buzzer_delay);
    this->buzzer_delay = map(distance, 20, 80, 150, 750)*1000;
  }

  void trigger() {
    if (this->buzzer_delay < 750000){
      if (current_time_buzzer - this->previous_time_buzzer >this->buzzer_delay) {
        this->previous_time_buzzer = current_time_buzzer;
        digitalWrite(this->pin, HIGH);
      }
      if (current_time_buzzer - this->previous_time_buzzer > this->buzzer_delay/2) {
        digitalWrite(this->pin, LOW);
      }
    }

    else{
      digitalWrite(this->pin, LOW);
    }
  }

};

// Instantiate an object of the class

// id trig echo
Sensor sensor1(1, 4, 5);
Sensor sensor2(2, 6, 7);
Sensor sensor3(3, 8, 9);
Sensor sensor4(4, 10, 11);
Sensor sensor5(5, 12, 13);
Sensor sensor6(6, 14, 15);
Sensor sensor7(7, 16, 17);
Sensor sensor8(8, 18, 19); // Analog pins designated digital pin names. 

// id, pin
Buzzer Buzzer1(1, 0);
Buzzer Buzzer2(2, 1);
Buzzer Buzzer3(3, 2);
Buzzer Buzzer4(4, 3);


void setup() {
  
  sensor1.setPins();
  sensor2.setPins();
  sensor3.setPins();
  sensor4.setPins();
  sensor5.setPins();
  sensor6.setPins();
  sensor7.setPins();
  sensor8.setPins();

  Buzzer1.setPins();
  Buzzer2.setPins();
  Buzzer3.setPins();
  Buzzer4.setPins();
}

void loop() {
  current_time_sensor = micros();
  current_time_buzzer = micros();
  sensor1.trigger();
  sensor2.trigger();
  sensor3.trigger();
  sensor4.trigger();
  sensor5.trigger();
  sensor6.trigger();
  sensor7.trigger();
  sensor8.trigger();

  Buzzer1.setDelay(sensor1.distance, sensor2.distance);
  Buzzer2.setDelay(sensor3.distance, sensor4.distance);
  Buzzer3.setDelay(sensor5.distance, sensor6.distance);
  Buzzer4.setDelay(sensor7.distance, sensor8.distance);

  Buzzer1.trigger();
  Buzzer2.trigger();
  Buzzer3.trigger();
  Buzzer4.trigger();

}

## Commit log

2024-08-23 Created folders and Initial Commits to abstraction, enclosure, justification, progress report and user manual
2024-08-24 Add files via upload
    Enclosure files by Lahiru
    [enclosure lid.SLDPRT]
2024-08-24 More final changes. Need to add power consumption and final pricing
2024-08-24 Drill bit info added
2024-08-24 PCB Initial Commit and Images Added
2024-08-24 Pitch Slide Added
2024-08-24 PCB Schematic added to folder and project report
2024-08-25 Power consumption info added to datasheet
2024-08-25 Pitch slide price changed to Rs. 9,999
2024-08-27 Slide Pitch final
2024-08-29 Power consumption fixed in manual and report and datasheet
2024-09-23 Expenses Sheet Added
    [Expenses.xlsm]
